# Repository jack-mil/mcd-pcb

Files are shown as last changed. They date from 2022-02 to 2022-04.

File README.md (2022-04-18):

# M68000 Single Board Computer PCB #

Kicad project files for pcb design

Designed with Kicad V6

Also included in `vhdl/` is the code for control logic in the CPLD

v1.0.0 goes with the monitor software developed in the [mcd-asm repository](https://github.com/jack-mil/mcd-asm/).

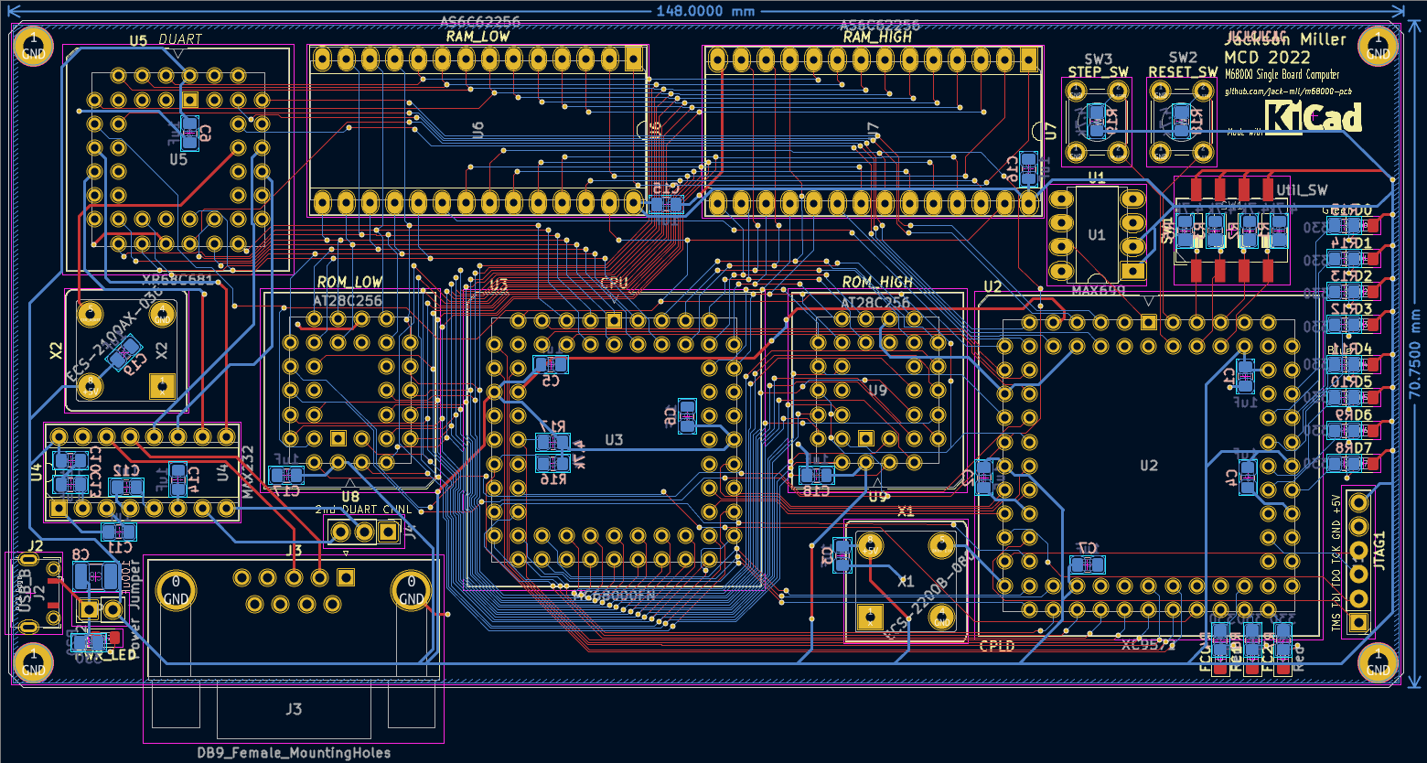
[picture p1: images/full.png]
pcb


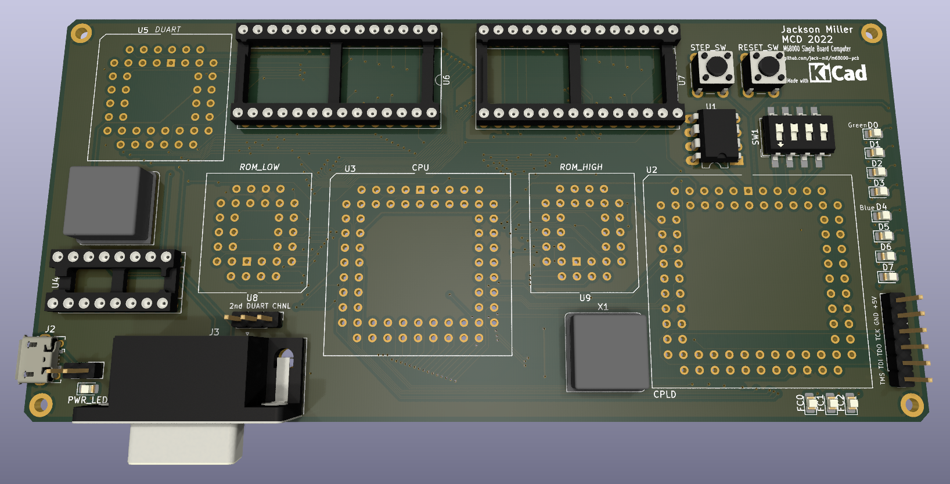
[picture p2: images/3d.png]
3d


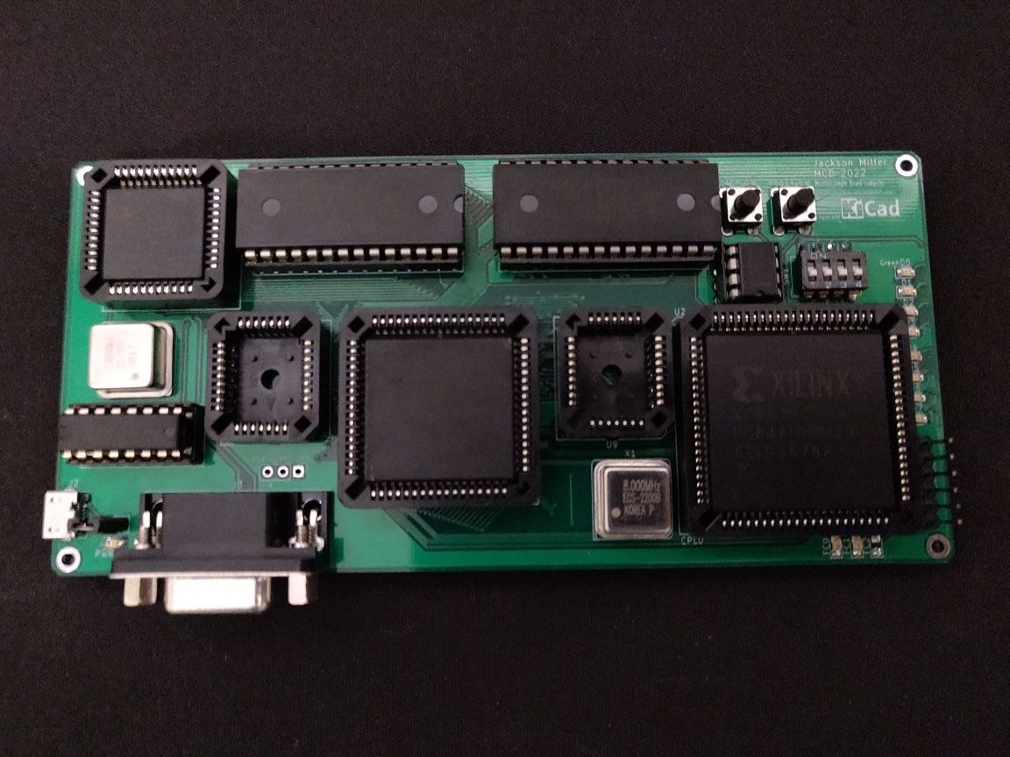
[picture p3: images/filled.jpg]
complete


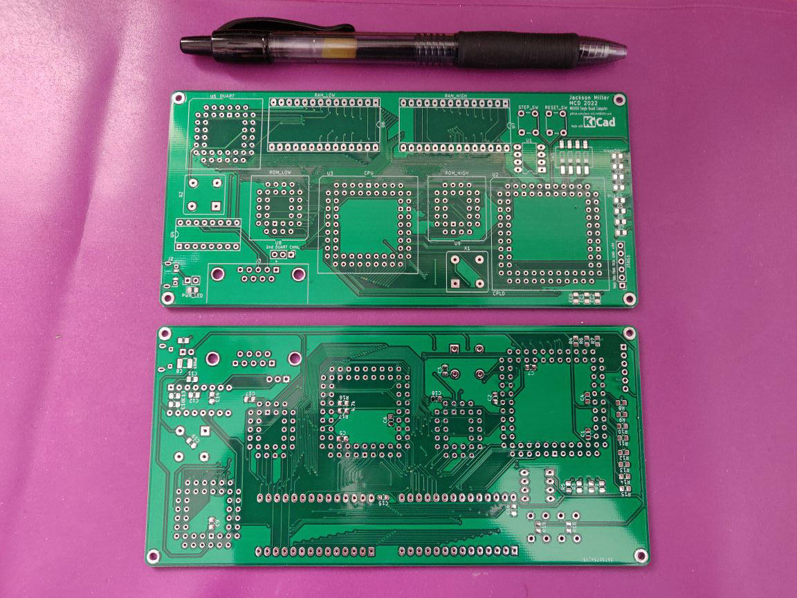
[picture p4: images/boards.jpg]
boards


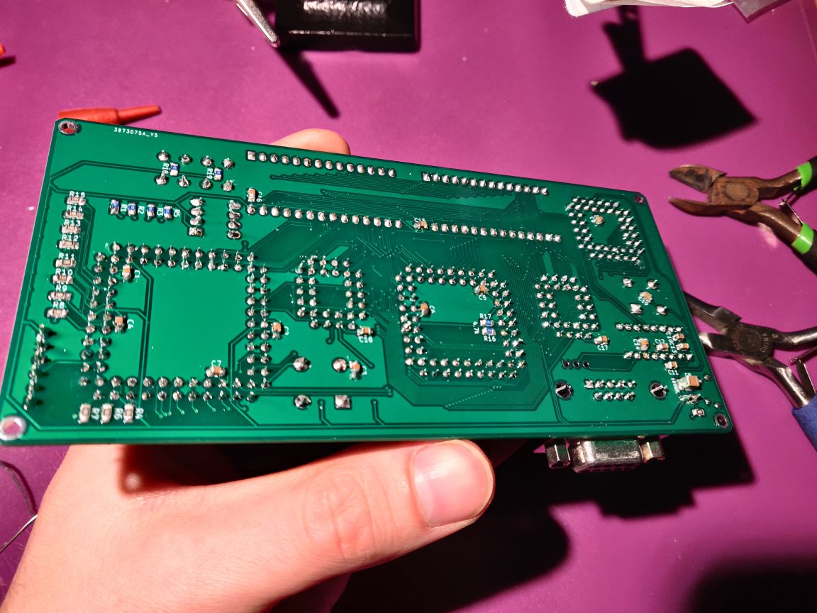
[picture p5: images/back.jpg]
back


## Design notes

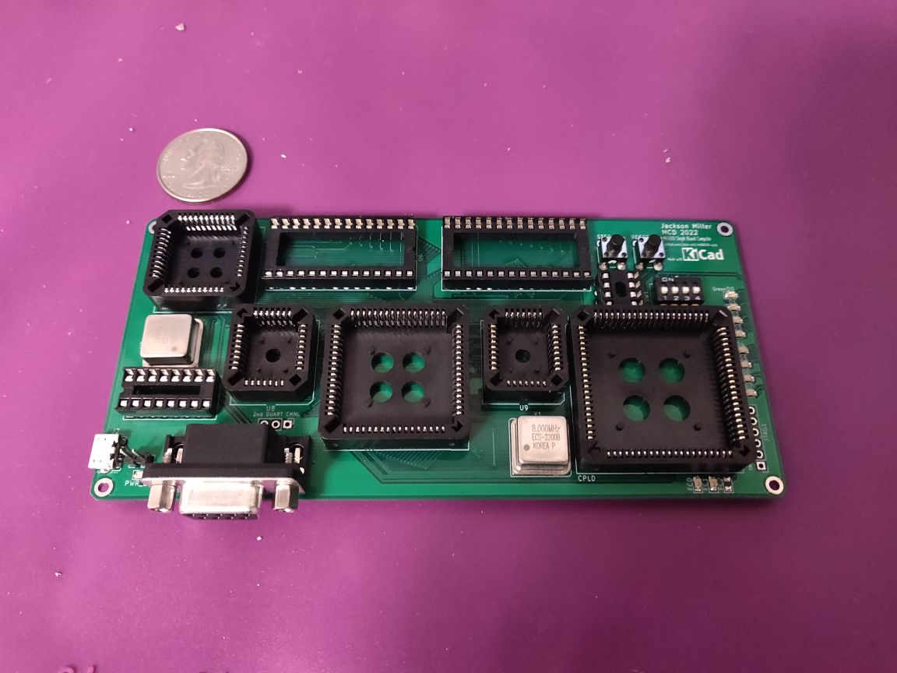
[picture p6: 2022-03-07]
images/no_ic.jpg

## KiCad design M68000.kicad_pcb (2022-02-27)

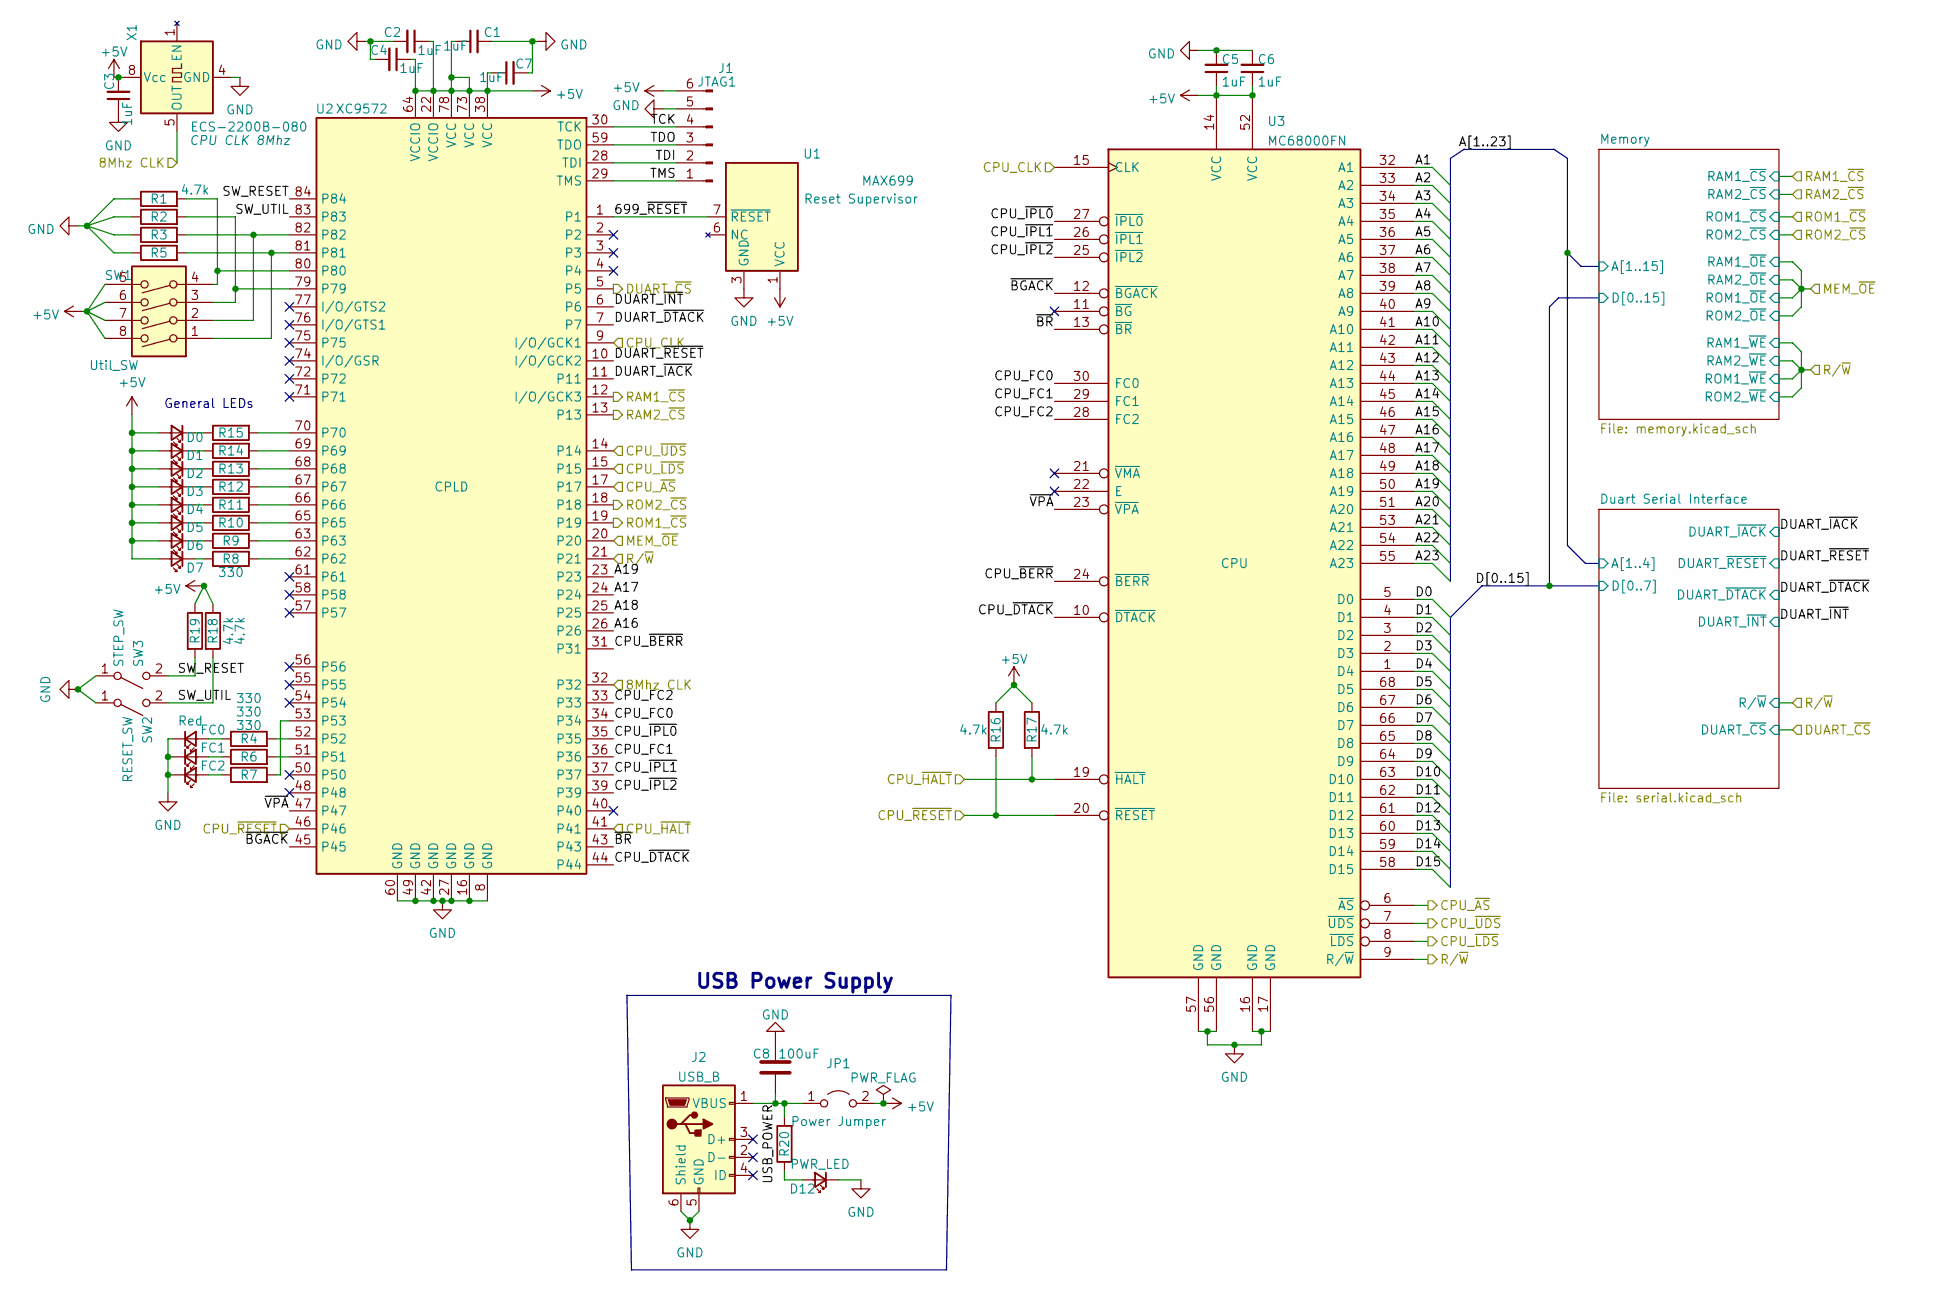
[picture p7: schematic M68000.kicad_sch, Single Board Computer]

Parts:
C1, C2, C3, C4, C5, C6, C7: 1uF; C_0805_2012Metric_Pad1.18x1.45mm_HandSolder
C8: 100uF; C_1210_3225Metric_Pad1.33x2.70mm_HandSolder
D0, D1, D2, D3: Green; LED_0805_2012Metric_Pad1.15x1.40mm_HandSolder
D4, D5, D6, D7: Blue; LED_0805_2012Metric_Pad1.15x1.40mm_HandSolder
D12: PWR_LED; LED_0805_2012Metric_Pad1.15x1.40mm_HandSolder
FC0, FC1, FC2: Red; LED_0805_2012Metric_Pad1.15x1.40mm_HandSolder
J1: JTAG1; JTAG PinHeader_1x06_P2.54mm_Vertical
J2: USB_B; USB_Micro-B_CS5A-NF
JP1: Power Jumper; PinHeader_1x02_P2.54mm_Vertical
R1, R2, R3, R5, R16, R17, R18, R19: 4.7k; R_0805_2012Metric_Pad1.20x1.40mm_HandSolder
R4, R6, R7, R8, R9, R10, R11, R12, R13, R14, R15, R20: 330; R_0805_2012Metric_Pad1.20x1.40mm_HandSolder
SW1: Util_SW; SW_DIP_SPSTx04_Slide_6.7x11.72mm_W8.61mm_P2.54mm_LowProfile
SW2: RESET_SW; SW_PUSH_6mm
SW3: STEP_SW; SW_PUSH_6mm
U1: MAX699; DIP-8_W7.62mm_LongPads
U2: XC9572; PLCC-84_THT-Socket
U3: MC68000FN; PLCC-68_THT-Socket
X1: ECS-2200B-080; Oscillator_DIP-8_LargePads

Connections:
+5V: C1.1, C2.1, C3.2, C4.1, C5.1, C6.1, C7.1, D0.2 (A), D1.2 (A), D2.2 (A), D3.2 (A), D4.2 (A), D5.2 (A), D6.2 (A), D7.2 (A), J1.6, JP1.2 (B), R16.1, R17.1, R18.1, R19.1, SW1.5, SW1.6, SW1.7, SW1.8, U1.1 (VCC), U1.2 (VCC), U2.22 (VCCIO), U2.38 (VCC), U2.64 (VCCIO), U2.73 (VCC), U2.78 (VCC), U3.14 (VCC), U3.52 (VCC), X1.8 (Vcc); also elsewhere on the board
/8Mhz CLK: U2.32, X1.5 (OUT)
/699_~RESET: U1.7 (~RESET), U2.1
/A1: U3.32 (A1); also elsewhere on the board
/A2: U3.33 (A2); also elsewhere on the board
/A3: U3.34 (A3); also elsewhere on the board
/A4: U3.35 (A4); also elsewhere on the board
/A5: U3.36 (A5); also elsewhere on the board
/A6: U3.37 (A6); also elsewhere on the board
/A7: U3.38 (A7); also elsewhere on the board
/A8: U3.39 (A8); also elsewhere on the board
/A9: U3.40 (A9); also elsewhere on the board
/A10: U3.41 (A10); also elsewhere on the board
/A11: U3.42 (A11); also elsewhere on the board
/A12: U3.43 (A12); also elsewhere on the board
/A13: U3.44 (A13); also elsewhere on the board
/A14: U3.45 (A14); also elsewhere on the board
/A15: U3.46 (A15); also elsewhere on the board
/A16: U2.26, U3.47 (A16)
/A17: U2.24, U3.48 (A17)
/A18: U2.25, U3.49 (A18)
/A19: U2.23, U3.50 (A19)
/A20: U3.51 (A20)
/A21: U3.53 (A21)
/A22: U3.54 (A22)
/A23: U3.55 (A23)
/CPU_CLK: U2.9 (I/O/GCK1), U3.15 (CLK)
/CPU_FC0: U2.34, U3.30 (FC0)
/CPU_FC1: U2.36, U3.29 (FC1)
/CPU_FC2: U2.33, U3.28 (FC2)
/CPU_~AS: U2.17, U3.6 (~AS)
/CPU_~BERR: U2.31, U3.24 (~BERR)
/CPU_~DTACK: U2.44, U3.10 (~DTACK)
/CPU_~HALT: R17.2, U2.41, U3.19 (~HALT)
/CPU_~IPL0: U2.35, U3.27 (~IPL0)
/CPU_~IPL1: U2.37, U3.26 (~IPL1)
/CPU_~IPL2: U2.39, U3.25 (~IPL2)
/CPU_~LDS: U2.15, U3.8 (~LDS)
/CPU_~RESET: R16.2, U2.46, U3.20 (~RESET)
/CPU_~UDS: U2.14, U3.7 (~UDS)
/D0: U3.5 (D0); also elsewhere on the board
/D1: U3.4 (D1); also elsewhere on the board
/D2: U3.3 (D2); also elsewhere on the board
/D3: U3.2 (D3); also elsewhere on the board
/D4: U3.1 (D4); also elsewhere on the board
/D5: U3.68 (D5); also elsewhere on the board
/D6: U3.67 (D6); also elsewhere on the board
/D7: U3.66 (D7); also elsewhere on the board
/D8: U3.65 (D8); also elsewhere on the board
/D9: U3.64 (D9); also elsewhere on the board
/D10: U3.63 (D10); also elsewhere on the board
/D11: U3.62 (D11); also elsewhere on the board
/D12: U3.61 (D12); also elsewhere on the board
/D13: U3.60 (D13); also elsewhere on the board
/D14: U3.59 (D14); also elsewhere on the board
/D15: U3.58 (D15); also elsewhere on the board
/DUART_~CS: U2.5; also elsewhere on the board
/DUART_~DTACK: U2.7; also elsewhere on the board
/DUART_~IACK: U2.11; also elsewhere on the board
/DUART_~INT: U2.6; also elsewhere on the board
/DUART_~RESET: U2.10 (I/O/GCK2); also elsewhere on the board
/MEM_~OE: U2.20; also elsewhere on the board
/RAM1_~CS: U2.12 (I/O/GCK3); also elsewhere on the board
/RAM2_~CS: U2.13; also elsewhere on the board
/ROM1_~CS: U2.19; also elsewhere on the board
/ROM2_~CS: U2.18; also elsewhere on the board
/R/~W: U2.21, U3.9 (R/~W); also elsewhere on the board
/SW_RESET: R19.2, SW3.2 (B), U2.84
/SW_UTIL: R18.2, SW2.2 (B), U2.83
/TCK: J1.4, U2.30 (TCK)
/TDI: J1.2, U2.28 (TDI)
/TDO: J1.3, U2.59 (TDO)
/TMS: J1.1, U2.29 (TMS)
/USB_POWER: C8.1, J2.1 (VBUS), JP1.1 (A), R20.2
/~BGACK: U2.45, U3.12 (~BGACK)
/~BR: U2.43, U3.13 (~BR)
/~VPA: U2.47, U3.23 (~VPA)
GND: C1.2, C2.2, C3.1, C4.2, C5.2, C6.2, C7.2, C8.2, D12.1 (K), FC0.1 (K), FC1.1 (K), FC2.1 (K), J1.5, J2.5 (GND), J2.6 (Shield), R1.1, R2.1, R3.1, R5.1, SW2.1 (A), SW3.1 (A), U1.3 (GND), U1.4 (GND), U1.8 (GND), U2.8 (GND), U2.16 (GND), U2.27 (GND), U2.42 (GND), U2.49 (GND), U2.60 (GND), U3.16 (GND), U3.17 (GND), U3.56 (GND), U3.57 (GND), X1.4 (GND); also elsewhere on the board
unnamed: D0.1 (K), R15.1
unnamed: D1.1 (K), R14.1
unnamed: D2.1 (K), R13.1
unnamed: D3.1 (K), R12.1
unnamed: D4.1 (K), R11.1
unnamed: D5.1 (K), R10.1
unnamed: D6.1 (K), R9.1
unnamed: D7.1 (K), R8.1
unnamed: D12.2 (A), R20.1
unnamed: FC0.2 (A), R4.1
unnamed: FC1.2 (A), R6.1
unnamed: FC2.2 (A), R7.1
unnamed: R1.2, SW1.4, U2.80
unnamed: R2.2, SW1.3, U2.79
unnamed: R3.2, SW1.2, U2.82
unnamed: R4.2, U2.52
unnamed: R5.2, SW1.1, U2.81
unnamed: R6.2, U2.51
unnamed: R7.2, U2.53
unnamed: R8.2, U2.62
unnamed: R9.2, U2.63
unnamed: R10.2, U2.65
unnamed: R11.2, U2.66
unnamed: R12.2, U2.67
unnamed: R13.2, U2.68
unnamed: R14.2, U2.69
unnamed: R15.2, U2.70

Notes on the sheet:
General LEDs
USB Power Supply

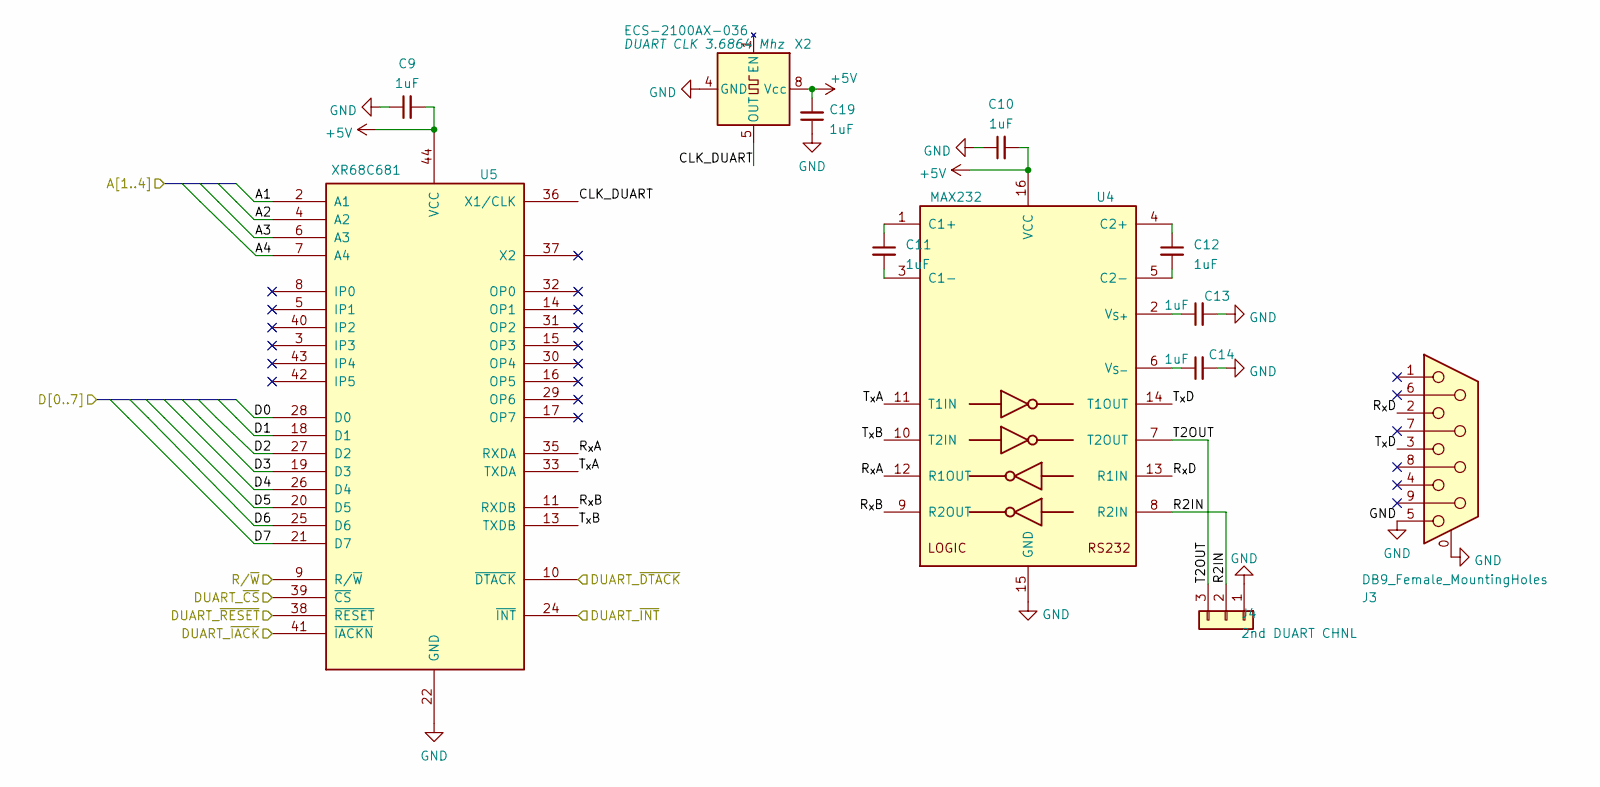
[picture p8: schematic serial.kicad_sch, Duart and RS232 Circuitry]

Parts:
C9, C10, C11, C12, C13, C14, C19: 1uF; C_0805_2012Metric_Pad1.18x1.45mm_HandSolder
J3: DB9_Female_MountingHoles; DSUB-9_Female_Horizontal_P2.77x2.84mm_EdgePinOffset7.70mm_H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
J4: 2nd DUART CHNL; PinHeader_1x03_P2.54mm_Vertical
U4: MAX232; DIP-16_W7.62mm_Socket
U5: XR68C681; PLCC-44_THT-Socket
X2: ECS-2100AX-036; Oscillator_DIP-8_LargePads

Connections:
+5V: C9.2, C10.2, C19.2, U4.16 (VCC), U5.44 (VCC), X2.8 (Vcc); also elsewhere on the board
/A1: U5.2 (A1); also elsewhere on the board
/A2: U5.4 (A2); also elsewhere on the board
/A3: U5.6 (A3); also elsewhere on the board
/A4: U5.7 (A4); also elsewhere on the board
/D0: U5.28 (D0); also elsewhere on the board
/D1: U5.18 (D1); also elsewhere on the board
/D2: U5.27 (D2); also elsewhere on the board
/D3: U5.19 (D3); also elsewhere on the board
/D4: U5.26 (D4); also elsewhere on the board
/D5: U5.20 (D5); also elsewhere on the board
/D6: U5.25 (D6); also elsewhere on the board
/D7: U5.21 (D7); also elsewhere on the board
/DUART_~CS: U5.39 (~CS); also elsewhere on the board
/DUART_~DTACK: U5.10 (~DTACK); also elsewhere on the board
/DUART_~IACK: U5.41 (~IACKN); also elsewhere on the board
/DUART_~INT: U5.24 (~INT); also elsewhere on the board
/DUART_~RESET: U5.38 (~RESET); also elsewhere on the board
/Duart Serial Interface/CLK_DUART: U5.36 (X1/CLK), X2.5 (OUT)
/Duart Serial Interface/R2IN: J4.2, U4.8 (R2IN)
/Duart Serial Interface/R_{x}A: U4.12 (R1OUT), U5.35 (RXDA)
/Duart Serial Interface/R_{x}B: U4.9 (R2OUT), U5.11 (RXDB)
/Duart Serial Interface/R_{x}D: J3.2, U4.13 (R1IN)
/Duart Serial Interface/T2OUT: J4.3, U4.7 (T2OUT)
/Duart Serial Interface/T_{x}A: U4.11 (T1IN), U5.33 (TXDA)
/Duart Serial Interface/T_{x}B: U4.10 (T2IN), U5.13 (TXDB)
/Duart Serial Interface/T_{x}D: J3.3, U4.14 (T1OUT)
/R/~W: U5.9 (R/~W); also elsewhere on the board
GND: C9.1, C10.1, C13.2, C14.2, C19.1, J3.0 (PAD), J3.5, J4.1, U4.15 (GND), U5.22 (GND), X2.4 (GND); also elsewhere on the board
unnamed: C11.1, U4.1 (C1+)
unnamed: C11.2, U4.3 (C1-)
unnamed: C12.1, U4.4 (C2+)
unnamed: C12.2, U4.5 (C2-)
unnamed: C13.1, U4.2 (V_{S+})
unnamed: C14.1, U4.6 (V_{S-})

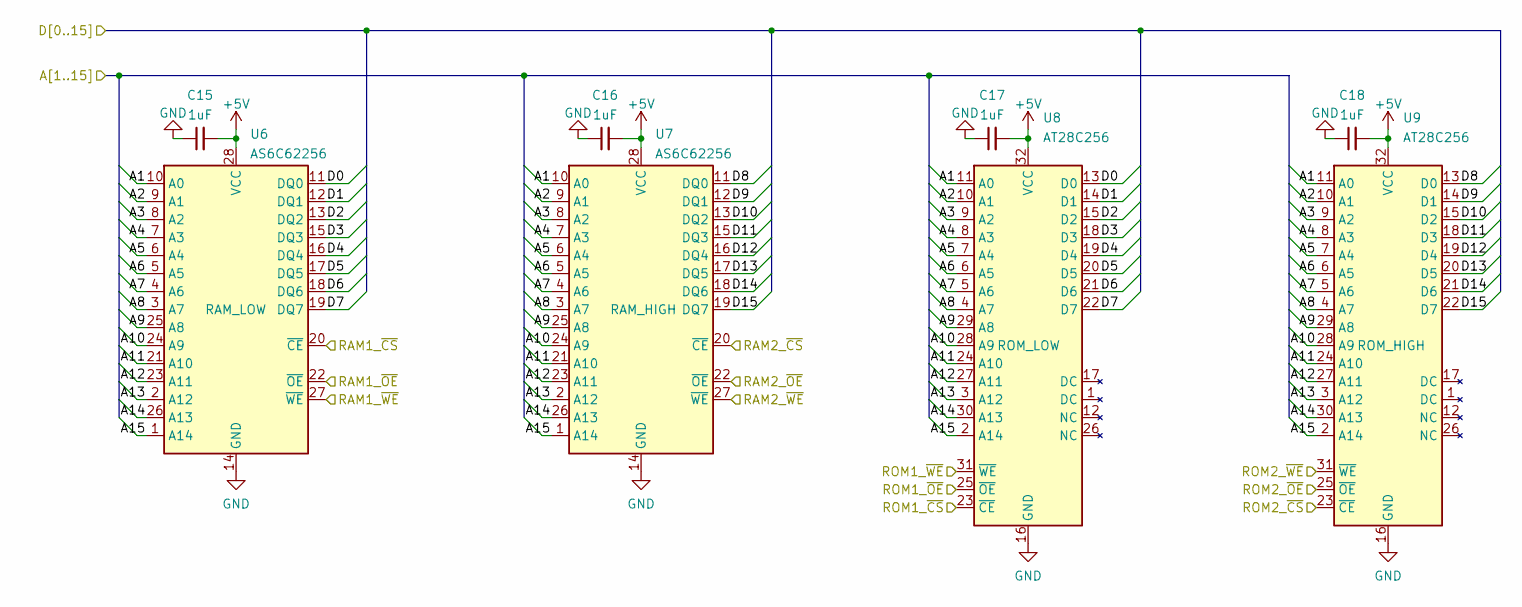
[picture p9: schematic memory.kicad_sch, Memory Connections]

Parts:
C15, C16, C17, C18: 1uF; C_0805_2012Metric_Pad1.18x1.45mm_HandSolder
U6, U7: AS6C62256; DIP-28_W15.24mm_Socket_LongPads
U8, U9: AT28C256; PLCC-32_THT-Socket

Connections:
+5V: C15.2, C16.2, C17.2, C18.2, U6.28 (VCC), U7.28 (VCC), U8.32 (VCC), U9.32 (VCC); also elsewhere on the board
/A1: U6.10 (A0), U7.10 (A0), U8.11 (A0), U9.11 (A0); also elsewhere on the board
/A2: U6.9 (A1), U7.9 (A1), U8.10 (A1), U9.10 (A1); also elsewhere on the board
/A3: U6.8 (A2), U7.8 (A2), U8.9 (A2), U9.9 (A2); also elsewhere on the board
/A4: U6.7 (A3), U7.7 (A3), U8.8 (A3), U9.8 (A3); also elsewhere on the board
/A5: U6.6 (A4), U7.6 (A4), U8.7 (A4), U9.7 (A4); also elsewhere on the board
/A6: U6.5 (A5), U7.5 (A5), U8.6 (A5), U9.6 (A5); also elsewhere on the board
/A7: U6.4 (A6), U7.4 (A6), U8.5 (A6), U9.5 (A6); also elsewhere on the board
/A8: U6.3 (A7), U7.3 (A7), U8.4 (A7), U9.4 (A7); also elsewhere on the board
/A9: U6.25 (A8), U7.25 (A8), U8.29 (A8), U9.29 (A8); also elsewhere on the board
/A10: U6.24 (A9), U7.24 (A9), U8.28 (A9), U9.28 (A9); also elsewhere on the board
/A11: U6.21 (A10), U7.21 (A10), U8.24 (A10), U9.24 (A10); also elsewhere on the board
/A12: U6.23 (A11), U7.23 (A11), U8.27 (A11), U9.27 (A11); also elsewhere on the board
/A13: U6.2 (A12), U7.2 (A12), U8.3 (A12), U9.3 (A12); also elsewhere on the board
/A14: U6.26 (A13), U7.26 (A13), U8.30 (A13), U9.30 (A13); also elsewhere on the board
/A15: U6.1 (A14), U7.1 (A14), U8.2 (A14), U9.2 (A14); also elsewhere on the board
/D0: U6.11 (DQ0), U8.13 (D0); also elsewhere on the board
/D1: U6.12 (DQ1), U8.14 (D1); also elsewhere on the board
/D2: U6.13 (DQ2), U8.15 (D2); also elsewhere on the board
/D3: U6.15 (DQ3), U8.18 (D3); also elsewhere on the board
/D4: U6.16 (DQ4), U8.19 (D4); also elsewhere on the board
/D5: U6.17 (DQ5), U8.20 (D5); also elsewhere on the board
/D6: U6.18 (DQ6), U8.21 (D6); also elsewhere on the board
/D7: U6.19 (DQ7), U8.22 (D7); also elsewhere on the board
/D8: U7.11 (DQ0), U9.13 (D0); also elsewhere on the board
/D9: U7.12 (DQ1), U9.14 (D1); also elsewhere on the board
/D10: U7.13 (DQ2), U9.15 (D2); also elsewhere on the board
/D11: U7.15 (DQ3), U9.18 (D3); also elsewhere on the board
/D12: U7.16 (DQ4), U9.19 (D4); also elsewhere on the board
/D13: U7.17 (DQ5), U9.20 (D5); also elsewhere on the board
/D14: U7.18 (DQ6), U9.21 (D6); also elsewhere on the board
/D15: U7.19 (DQ7), U9.22 (D7); also elsewhere on the board
/MEM_~OE: U6.22 (~OE), U7.22 (~OE), U8.25 (~OE), U9.25 (~OE); also elsewhere on the board
/RAM1_~CS: U6.20 (~CE); also elsewhere on the board
/RAM2_~CS: U7.20 (~CE); also elsewhere on the board
/ROM1_~CS: U8.23 (~CE); also elsewhere on the board
/ROM2_~CS: U9.23 (~CE); also elsewhere on the board
/R/~W: U6.27 (~WE), U7.27 (~WE), U8.31 (~WE), U9.31 (~WE); also elsewhere on the board
GND: C15.1, C16.1, C17.1, C18.1, U6.14 (GND), U7.14 (GND), U8.16 (GND), U9.16 (GND); also elsewhere on the board

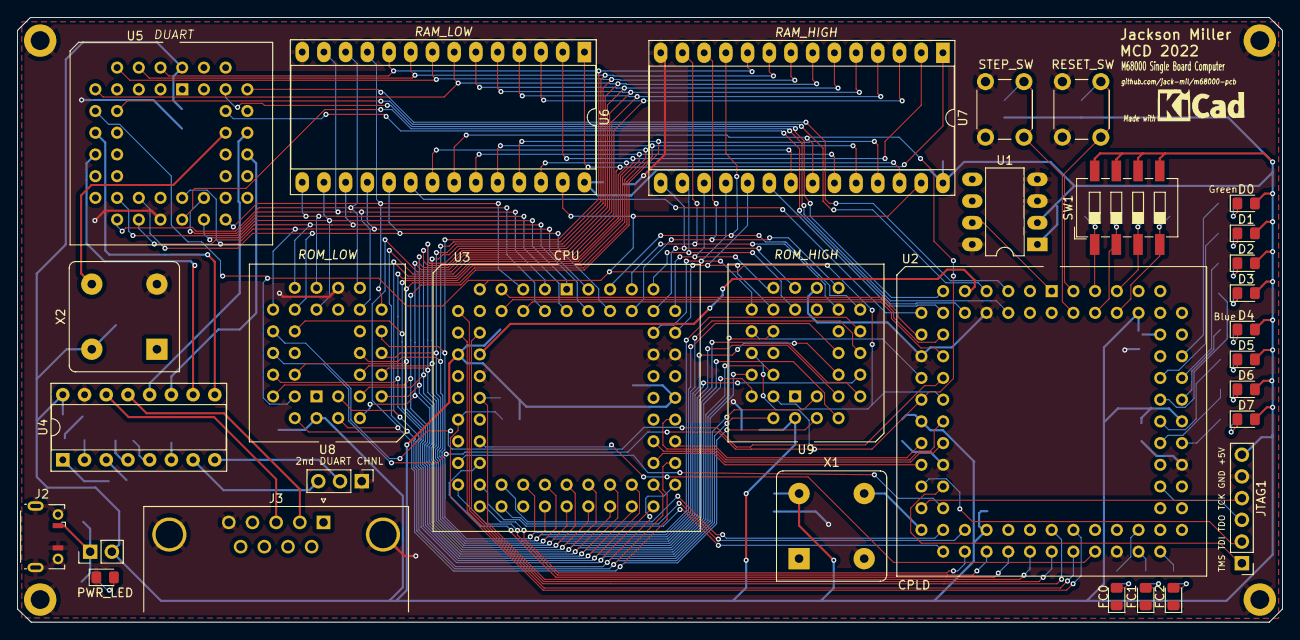
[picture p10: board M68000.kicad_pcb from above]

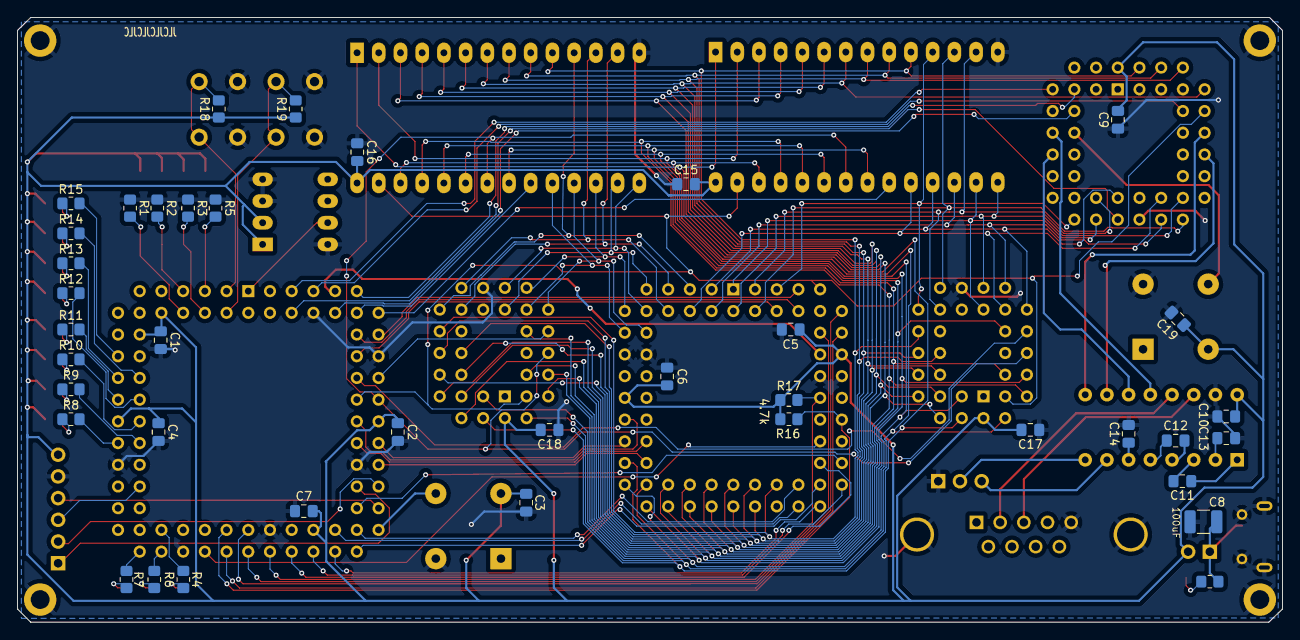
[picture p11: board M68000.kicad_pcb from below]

Board: 2 copper layers, 148.0 x 70.8 mm, 70 parts (39 on the bottom side), 116 nets.

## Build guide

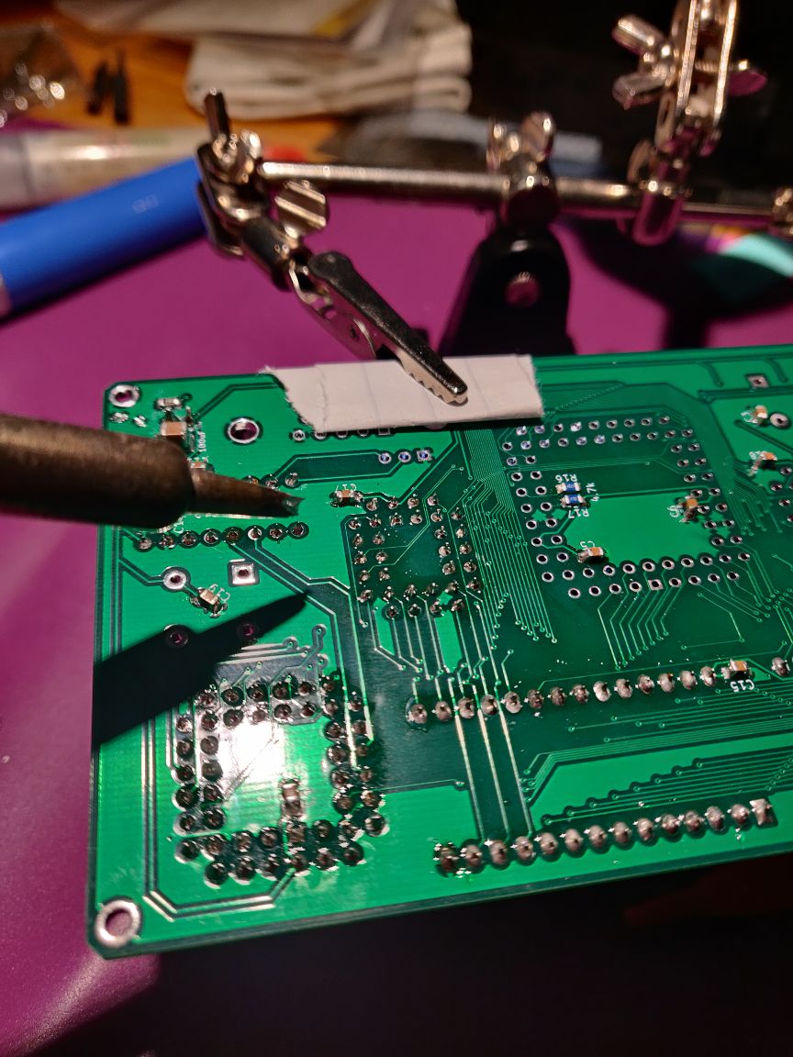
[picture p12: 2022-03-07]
images/soldering.jpg

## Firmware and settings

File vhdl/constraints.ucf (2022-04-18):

NET DUART_CS LOC=P5;
NET DUART_INT LOC=P6;
NET DUART_DTACK LOC=P7;
NET DUART_RESET LOC=P10;
NET DUART_IACK LOC=P11;

NET CLK_IN LOC=P32;

NET SUP_RESET LOC=P1;

NET CPU_CLK LOC=P9;
NET CPU_HALT LOC=P41;
NET CPU_RESET LOC=P46;

NET RAML_CS LOC=P12;
NET RAMH_CS LOC=P13;
NET ROML_CS LOC=P19;
NET ROMH_CS LOC=P18;

NET MEM_OE LOC=P20;

NET CPU_AS LOC=P17;
NET CPU_RW LOC=P21;
NET CPU_UDS LOC=P14;
NET CPU_LDS LOC=P15;
NET CPU_DTACK LOC=P44;
NET CPU_BERR LOC=P31;

NET CPU_BR LOC=P43;
NET CPU_BGACK LOC=P45;

NET CPU_VPA LOC=P47;

NET ADDR<0> LOC=P26;
NET ADDR<1> LOC=P24;
NET ADDR<2> LOC=P25;
NET ADDR<3> LOC=P23;

NET CPU_FC<0> LOC=P34;
NET CPU_FC<1> LOC=P36;
NET CPU_FC<2> LOC=P33;

NET CPU_IPL<0> LOC=P35;
NET CPU_IPL<1> LOC=P37;
NET CPU_IPL<2> LOC=P39;


NET FC_LED<0> LOC=P52;
NET FC_LED<1> LOC=P51;
NET FC_LED<2> LOC=P53;

NET LED_G<0> LOC=P70;
NET LED_G<1> LOC=P69;
NET LED_G<2> LOC=P68;
NET LED_G<3> LOC=P67;

NET LED_B<0> LOC=P66;
NET LED_B<1> LOC=P65;
NET LED_B<2> LOC=P63;
NET LED_B<3> LOC=P62;

NET DIP_SW<0> LOC=P81;
NET DIP_SW<1> LOC=P82;
NET DIP_SW<2> LOC=P79;
NET DIP_SW<3> LOC=P80;

NET SW_RESET LOC=P83;
NET SW_UTIL LOC=P84;

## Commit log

2022-02-02 All parts and begin schematics
    [M68000.kicad_sch, memory.kicad_sch, serial.kicad_sch]
2022-02-23 Final PCB Layout
    [M68000.kicad_pcb, M68000.kicad_sch, memory.kicad_sch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]
2022-02-27 Submitted to JLCPCB
    [M68000.kicad_pcb, M68000.kicad_sch, memory.kicad_sch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]
2022-03-07 Rename Memory to match High/Low
    [M68000.kicad_sch, memory.kicad_sch]
2022-04-13 PCB v1 final design
    [M68000.kicad_sch]
